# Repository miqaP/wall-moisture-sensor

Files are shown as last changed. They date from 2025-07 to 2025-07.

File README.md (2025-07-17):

# wall-moisture-sensor
https://github.com/miqaP/wall-moisture-sensor

# Versionning
Pour le moment j'ai une branche dev. Comment  
- Dev -> Release 

## Version de carte
Il faut se placer du point de vue de la carte et peut-être mettre de côté l'impact sur le firmware

- MAJOR -> Modification importantes -> Changement dans les fonctionnalités du produit -> feat:
    - Ajout d'une fonctionnalitées. Est-ce que l'ajout d'un connecteur est une nouvelle fonctionnalité ? Non je ne crois pas
    - Suppression d'une fonctionnalitées

- MINOR -> Pas de modification de fonctionnalité -> design:
    - Modification de composant, qui necessite la modification du routage par exemple changement de référence d'un DC/DC -> Mais pas de changement dans la fonctionnalité
    - Optimisation du layout, déplacement des composants
    - Changement du layout pour s'intégrer dans un boitier
    - Changement de la sérigraphie
- PATCH -> Modification de la BOM -> bom
    - Ok mais des fois la modification de la BOM implique une modification du firmware, nan ?

# Continuous Integration
Voir https://sschueller.github.io/posts/ci-cd-with-kicad-and-gitlab/
https://github.com/LiveLeds/AstraDriver/tree/main

Liste des commandes qui doivent être lancées par la CI : 
- kicad-cli pcb drc wall_moisture-hardware.kicad_pcb
-  kicad-cli pcb export gerbers wall_moisture-hardware.kicad_pcb -o gerbers/
- kicad-cli render wall_moisture-hardware
- kicad-cli render wall_moisture-hardware.kicad_pcb
- kicad-cli pcb render wall_moisture-hardware.kicad_pcb
- kicad-cli pcb render wall_moisture-hardware.kicad_pcb --output 3drender/top.png -> Il faut faire les autres vues, les orientations et distances de la caméra vont dépendre de la taille du projet. Un script python pourrait determiner ces informations

L'intégration se lance lors de la création d'une release

Chose a réaliser: 
- Un rapport de release qui montre la différence entre la version actuelle et la version précedente -> Voir Kicad-diff
    - Il faut pouvoir détérminer la version précédente, comment faire ?
- Exporter les pdf des schémas et du hardware ( les couches du PCB et la carte complète)

# Note sur la configuration du projet
Commitlint s’exécute à chaque commit grâce au hook Git commit-msg. Ce hook est un script situé dans le dossier .git/hooks/commit-msg qui est automatiquement lancé par Git à la validation d’un commit. Ce script appelle Commitlint pour vérifier que le message du commit respecte les règles définies.

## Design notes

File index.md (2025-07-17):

---
layout: home
title: Home
---

{% assign project = site.project %}
{% assign cacheBust = site.time | date:'?v=%s' %}

Main Render

{{ project.description }}




## Table of Contents
{% for section in project.sections %}
- [{{ section.title }}](#{{ section.anchor }})
{% endfor %}

{% for render in project.renders %}
### {{ render.title }}
{{ render.title }}
{% endfor %}

### Schematic
{% for variant in project.schematic_variants %}
- [{{ variant.name }} PDF]({{ "/documents/" | append: project.name | append: variant.file_suffix | absolute_url | append: cacheBust }})
{% endfor %}

### Assembly
{% for variant in project.assembly_variants %}
- [{{ variant.name }} PDF]({{ "/documents/" | append: project.name | append: variant.file_suffix | absolute_url | append: cacheBust }})
{% endfor %}

### Interactive BOM
[IBOM HTML]({{ "/export/" | append: project.name | append: "-ibom.html" | absolute_url | append: cacheBust }})

### BOM
[BOM HTML]({{ "/export/" | append: project.name | append: "-bom.html" | absolute_url | append: cacheBust }})

### Downloads
{% for manufacturer in project.manufacturers %}
#### {{ manufacturer }}
- [{{ manufacturer }} Zip]({{ "export/" | append: project.name | append: "-" | append: manufacturer | append: ".zip" | absolute_url | append: cacheBust }})
- [BOM CSV]({{ "export/" | append: project.name | append: "_bom_" | append: manufacturer | downcase | append: ".csv" | absolute_url | append: cacheBust }})
- [CPL CSV]({{ "export/" | append: project.name | append: "_cpl_" | append: manufacturer | downcase | append: ".csv" | absolute_url | append: cacheBust }})
{% endfor %}

#### 3D Step
- [STEP File]({{ "/" | append: project.name | append: "-3D.step" | absolute_url | append: cacheBust }})

## Reports
{% include_relative erc_validation.md %}
{% include_relative drc_validation.md %}
{% include_relative report.md %}

{% if project.known_issues %}
## Known Issues
{{ project.known_issues | markdownify }}
{% endif %}

## Credits
{{ project.credits | markdownify }}

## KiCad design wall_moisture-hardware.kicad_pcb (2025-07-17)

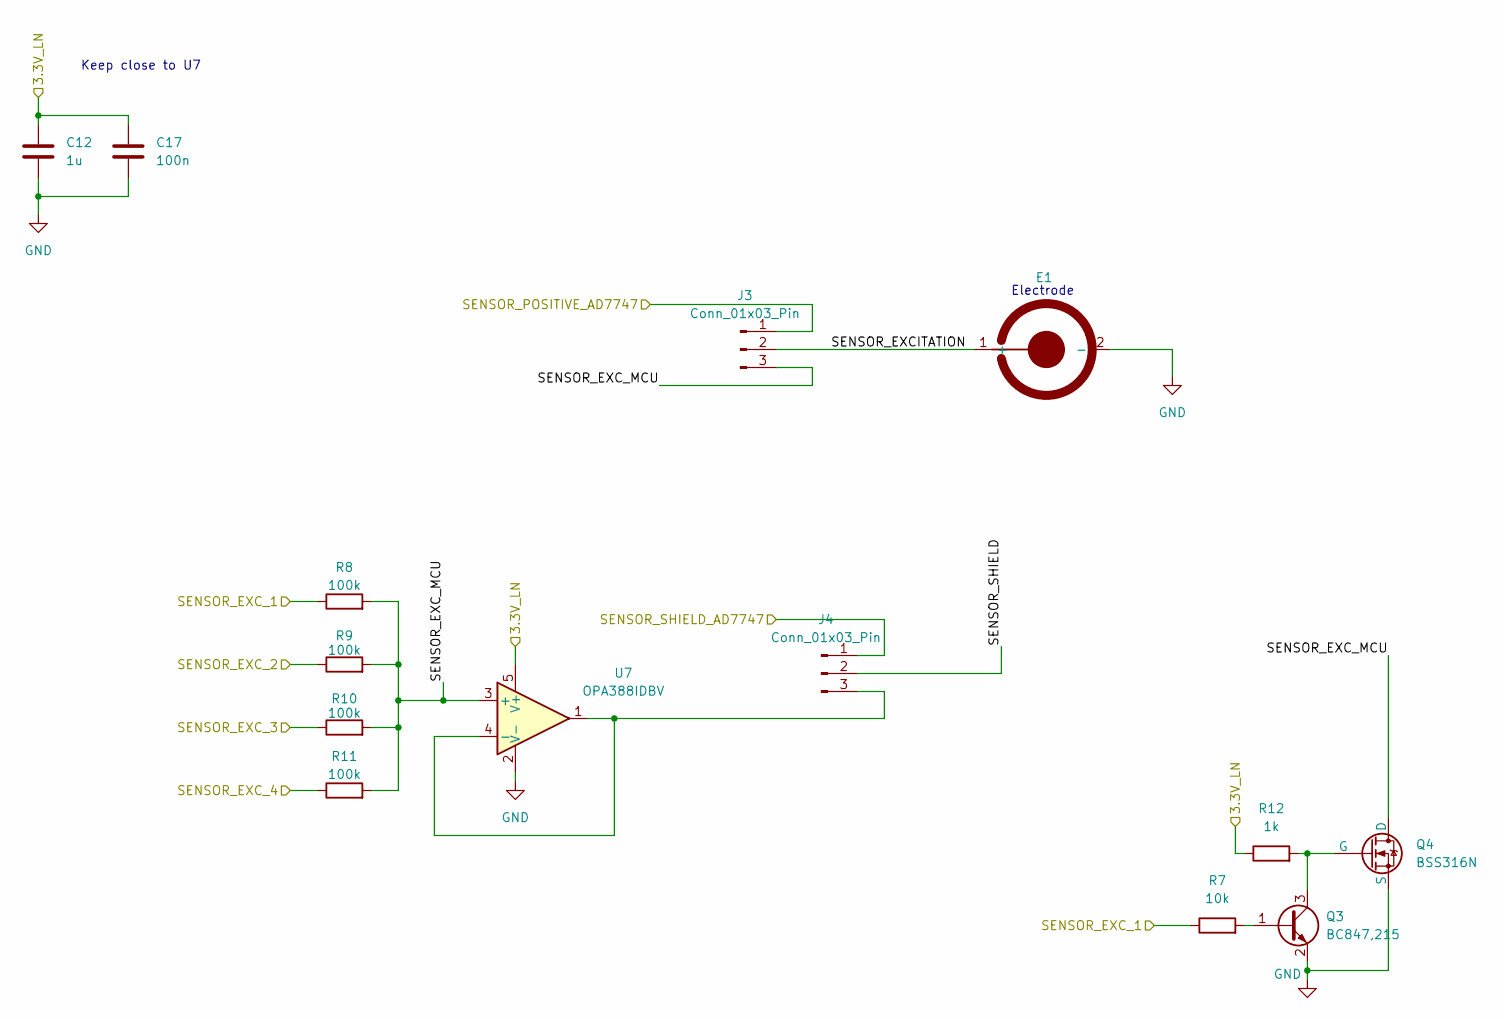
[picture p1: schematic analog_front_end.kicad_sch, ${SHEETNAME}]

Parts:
C12: 1u; C_0603_1608Metric
C17: 100n; C_0603_1608Metric
E1: CapacitiveElectrode-round_20mmx70mm
J3, J4: Conn_01x03_Pin; PinHeader_1x03_P2.54mm_Vertical
Q3: BC847,215; SOT-23
Q4: BSS316N; SOT-23
R7: 10k; R_0603_1608Metric
R8, R9, R10, R11: 100k; R_0603_1608Metric
R12: 1k; R_0603_1608Metric
U7: OPA388IDBV; SOT-23-5

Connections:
/Analog frontend/3.3V_LN: C12.1, C17.1, R12.1, U7.5 (V+); also elsewhere on the board
/Analog frontend/SENSOR_EXCITATION: E1.1 (+), J3.2
/Analog frontend/SENSOR_EXC_MCU: J3.3, Q4.1 (D), R8.2, R9.2, R10.2, R11.2, U7.3 (+)
/Analog frontend/SENSOR_POSITIVE_AD7747: J3.1; also elsewhere on the board
/Analog frontend/SENSOR_SHIELD: J4.2
/Analog frontend/SENSOR_SHIELD_AD7747: J4.1; also elsewhere on the board
/µC and digital/TIM1_CH1: R7.1, R8.1; also elsewhere on the board
/µC and digital/TIM1_CH2: R9.1; also elsewhere on the board
/µC and digital/TIM1_CH3: R10.1; also elsewhere on the board
/µC and digital/TIM1_CH4: R11.1; also elsewhere on the board
GND: C12.2, C17.2, E1.2 (-), Q3.2 (E), Q4.3 (S), U7.2 (V-); also elsewhere on the board
unnamed: J4.3, U7.1, U7.4 (-)
unnamed: Q3.1 (B), R7.2
unnamed: Q3.3 (C), Q4.2 (G), R12.2

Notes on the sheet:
Keep close to U7
Electrode

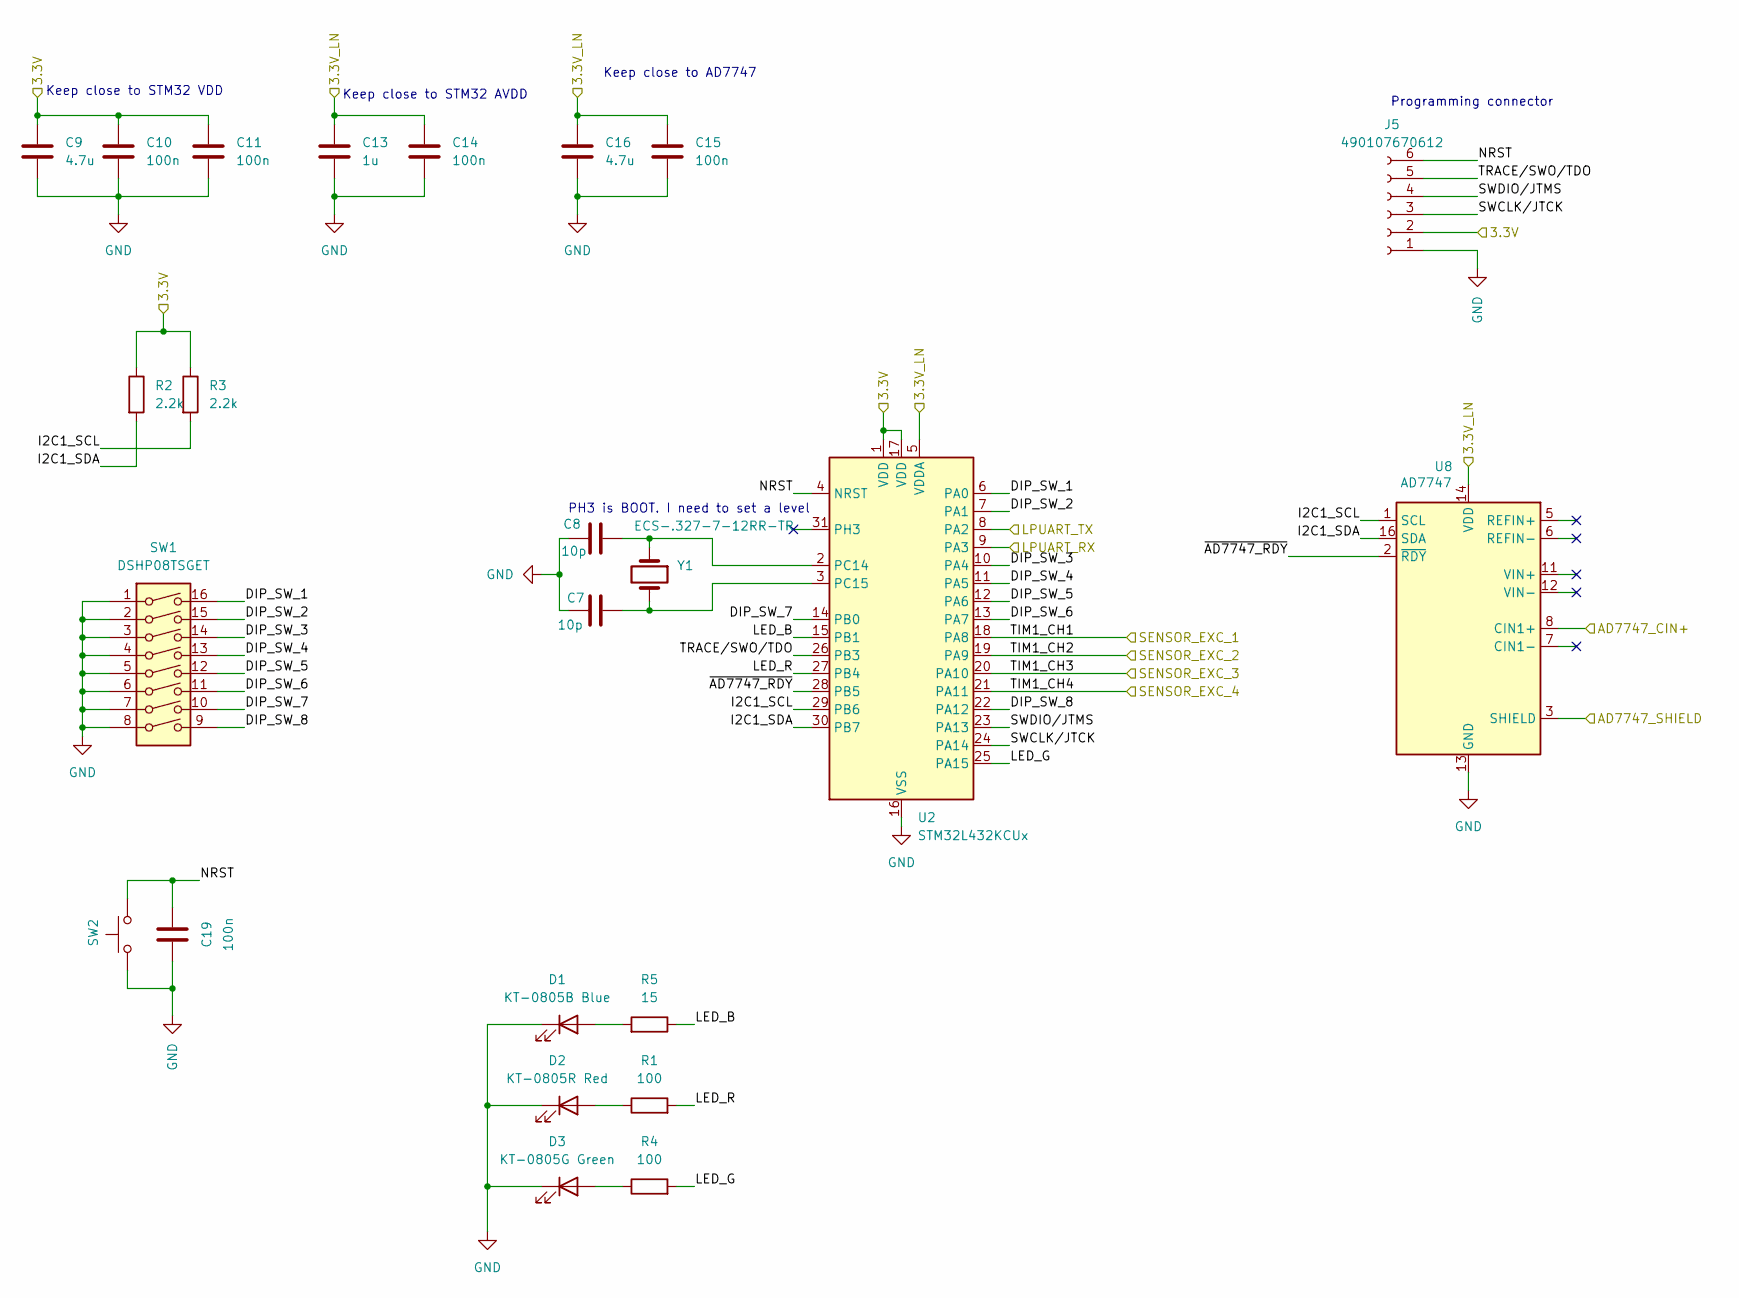
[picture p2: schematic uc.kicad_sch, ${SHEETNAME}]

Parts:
C7, C8: 10p; C_0603_1608Metric
C9, C16: 4.7u; C_0603_1608Metric
C10, C11, C14, C15, C19: 100n; C_0603_1608Metric
C13: 1u; C_0603_1608Metric
D1: KT-0805B Blue; LED_0805_2012Metric; LCSC C2293
D2: KT-0805R Red; LED_0805_2012Metric; LCSC C2295
D3: KT-0805G Green; LED_0805_2012Metric; LCSC C2297
J5: 490107670612; Skedd490107670612_2x06_P2.54mm_Debug
R1, R4: 100; R_0603_1608Metric
R2, R3: 2.2k; R_0603_1608Metric
R5: 15; R_0603_1608Metric
SW1: DSHP08TSGET; SW_DIP_SPSTx08_Slide_KingTek_DSHP08TJ_W5.25mm_P1.27mm_JPin
SW2: FSMH; SW_Tactile_SPST_NO_Straight_CK_PTS636Sx25SMTRLFS
U2: STM32L432KCUx; QFN-32-1EP_5x5mm_P0.5mm_EP3.45x3.45mm
U8: AD7747; TSSOP-16_4.4x5mm_P0.65mm
Y1: ECS-.327-7-12RR-TR; Crystal_SMD_2012-2Pin_2.0x1.2mm

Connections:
/Analog frontend/3.3V_LN: C13.1, C14.1, C15.1, C16.1, U2.5 (VDDA), U8.14 (VDD); also elsewhere on the board
/Analog frontend/SENSOR_POSITIVE_AD7747: U8.8 (CIN1+); also elsewhere on the board
/Analog frontend/SENSOR_SHIELD_AD7747: U8.3 (SHIELD); also elsewhere on the board
/Connector and Power/3.3V: C9.1, C10.1, C11.1, J5.2, R2.1, R3.1, U2.1 (VDD), U2.17 (VDD); also elsewhere on the board
/Connector and Power/MASTER_RX: U2.8 (PA2); also elsewhere on the board
/Connector and Power/MASTER_TX: U2.9 (PA3); also elsewhere on the board
/µC and digital/DIP_SW_1: SW1.16, U2.6 (PA0)
/µC and digital/DIP_SW_2: SW1.15, U2.7 (PA1)
/µC and digital/DIP_SW_3: SW1.14, U2.10 (PA4)
/µC and digital/DIP_SW_4: SW1.13, U2.11 (PA5)
/µC and digital/DIP_SW_5: SW1.12, U2.12 (PA6)
/µC and digital/DIP_SW_6: SW1.11, U2.13 (PA7)
/µC and digital/DIP_SW_7: SW1.10, U2.14 (PB0)
/µC and digital/DIP_SW_8: SW1.9, U2.22 (PA12)
/µC and digital/I2C1_SCL: R3.2, U2.29 (PB6), U8.1 (SCL)
/µC and digital/I2C1_SDA: R2.2, U2.30 (PB7), U8.16 (SDA)
/µC and digital/LED_B: R5.1, U2.15 (PB1)
/µC and digital/LED_G: R4.2, U2.25 (PA15)
/µC and digital/LED_R: R1.2, U2.27 (PB4)
/µC and digital/NRST: C19.2, J5.6, SW2.2, U2.4 (NRST)
/µC and digital/SWCLK/JTCK: J5.3, U2.24 (PA14)
/µC and digital/SWDIO/JTMS: J5.4, U2.23 (PA13)
/µC and digital/TIM1_CH1: U2.18 (PA8); also elsewhere on the board
/µC and digital/TIM1_CH2: U2.19 (PA9); also elsewhere on the board
/µC and digital/TIM1_CH3: U2.20 (PA10); also elsewhere on the board
/µC and digital/TIM1_CH4: U2.21 (PA11); also elsewhere on the board
/µC and digital/TRACE/SWO/TDO: J5.5, U2.26 (PB3)
/µC and digital/~AD7747_RDY: U2.28 (PB5), U8.2 (~RDY)
GND: C7.1, C8.1, C9.2, C10.2, C11.2, C13.2, C14.2, C15.2, C16.2, C19.1, D1.1 (K), D2.1 (K), D3.1 (K), J5.1, SW1.1, SW1.2, SW1.3, SW1.4, SW1.5, SW1.6, SW1.7, SW1.8, SW2.1, U2.16 (VSS), U2.32 (VSS), U2.33 (VSS), U8.13 (GND); also elsewhere on the board
unnamed: D1.2 (A), R5.2
unnamed: D2.2 (A), R1.1
unnamed: D3.2 (A), R4.1
unnamed: C8.2, U2.2 (PC14), Y1.1
unnamed: C7.2, U2.3 (PC15), Y1.2

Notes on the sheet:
Keep close to STM32 VDD
Programming connector
Keep close to AD7747
Keep close to STM32 AVDD
PH3 is BOOT. I need to set a level

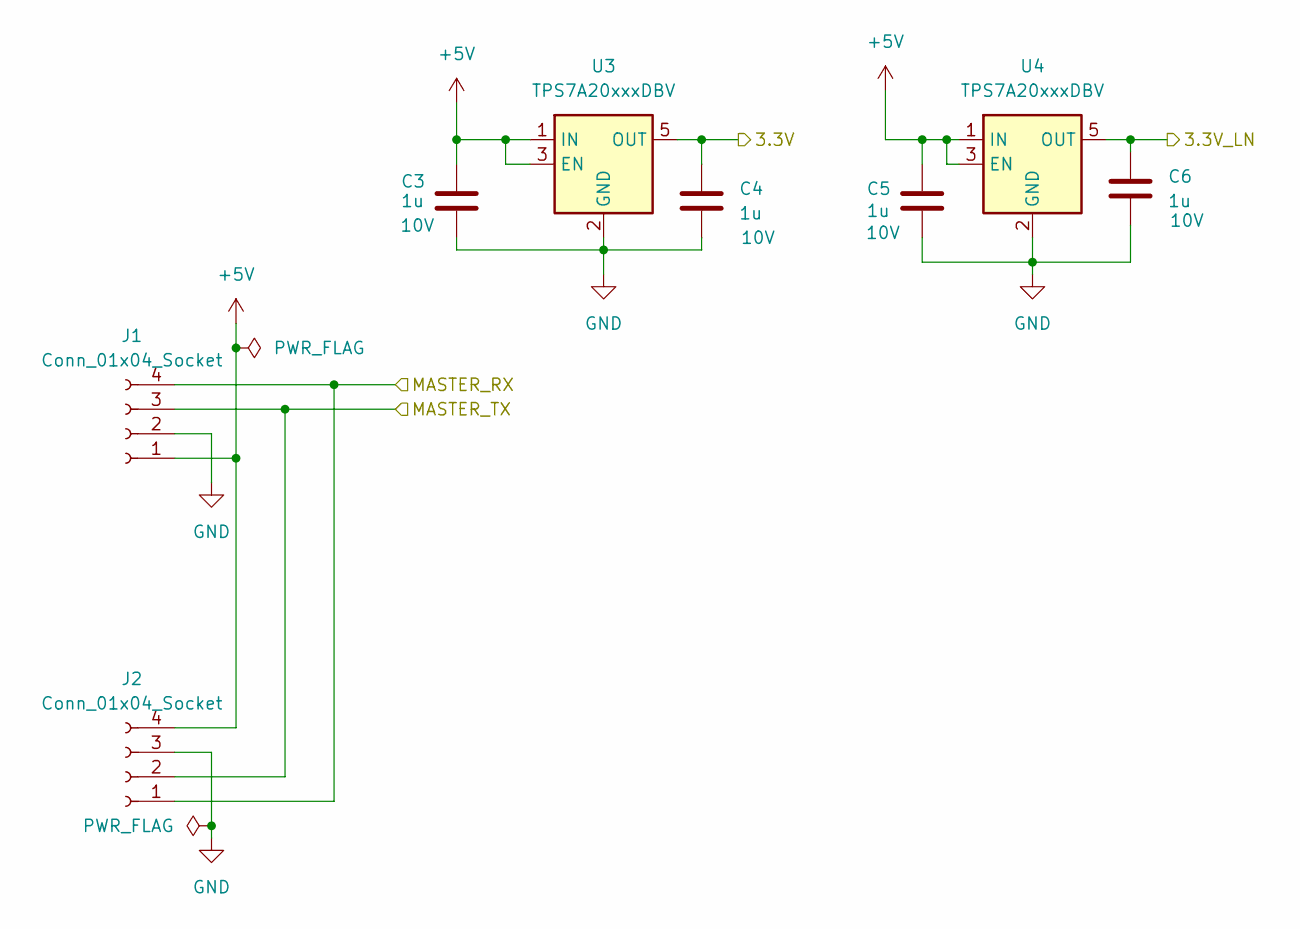
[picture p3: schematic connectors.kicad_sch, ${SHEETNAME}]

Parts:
C3, C4, C5, C6: 1u; C_0603_1608Metric
J1, J2: Conn_01x04_Socket; JST_PH_S4B-PH-SM4-TB_1x04-1MP_P2.00mm_Horizontal
U3, U4: TPS7A20xxxDBV; SOT-23-5

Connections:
+5V: C3.1, C5.1, J1.1, J2.4, U3.1 (IN), U3.3 (EN), U4.1 (IN), U4.3 (EN)
/Analog frontend/3.3V_LN: C6.1, U4.5 (OUT); also elsewhere on the board
/Connector and Power/3.3V: C4.1, U3.5 (OUT); also elsewhere on the board
/Connector and Power/MASTER_RX: J1.4, J2.1; also elsewhere on the board
/Connector and Power/MASTER_TX: J1.3, J2.2; also elsewhere on the board
GND: C3.2, C4.2, C5.2, C6.2, J1.2, J2.3, U3.2 (GND), U4.2 (GND); also elsewhere on the board

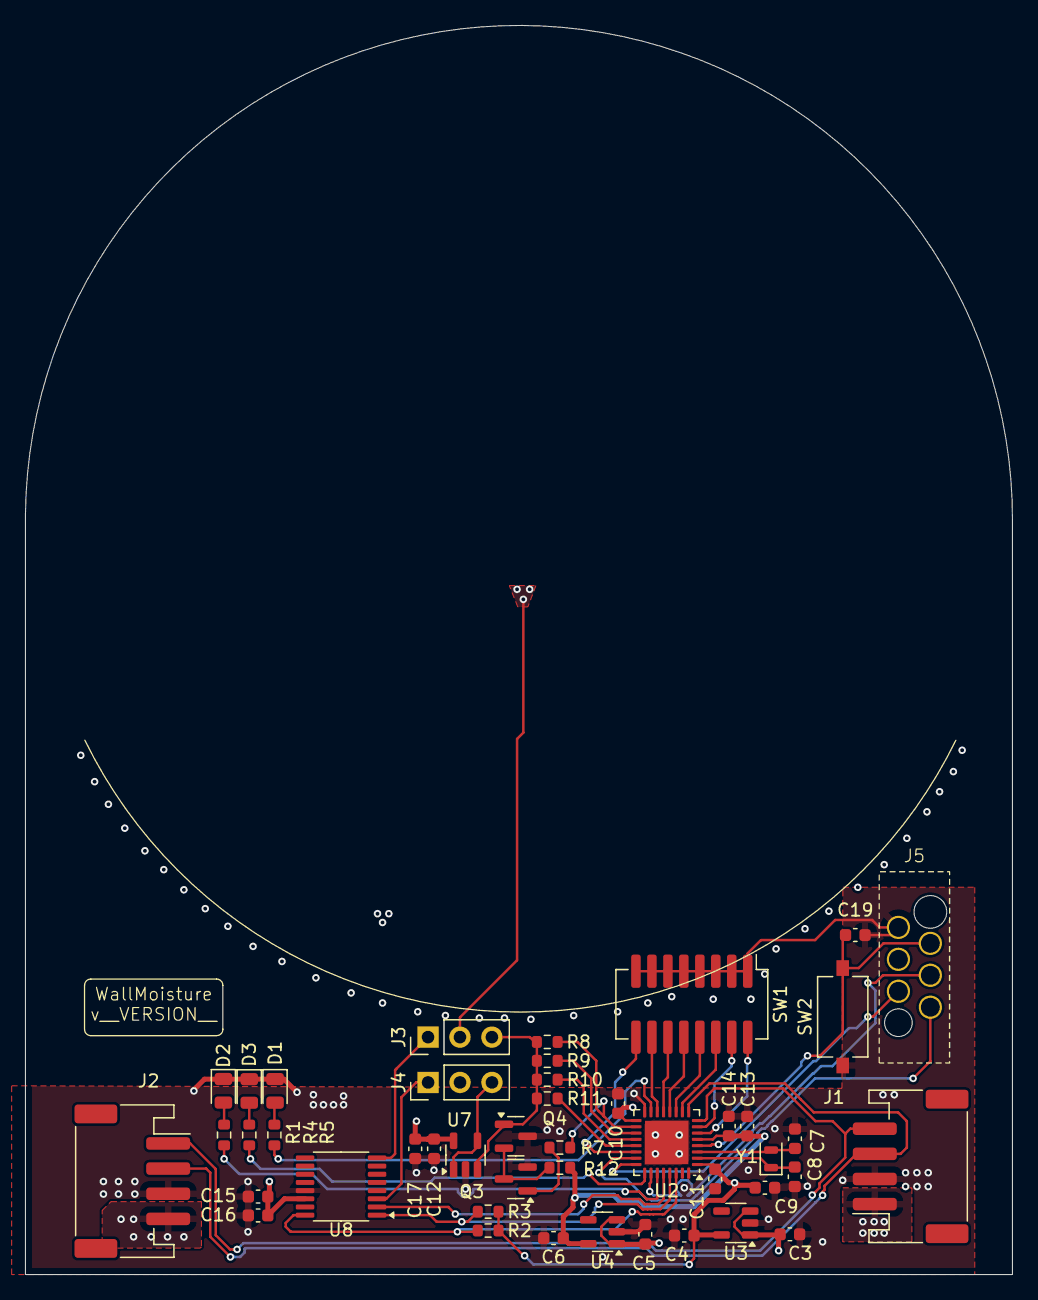
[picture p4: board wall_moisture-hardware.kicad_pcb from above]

Board: 4 copper layers, 78.5 x 99.3 mm, 46 parts (1 on the bottom side), 40 nets.

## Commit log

2025-04-05 First commit :
    [Connector.kicad_sch, analog_front_end.kicad_sch, uc.kicad_sch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]
2025-05-05 ci: Fix kibot pcb print configuration
2025-05-05 ci: fix pcb pdf path
2025-05-14 Fix board cutt layer
    [wall_moisture-hardware.kicad_pcb]
2025-05-14 design: fix board cut layer
    [wall_moisture-hardware.kicad_pcb]
2025-05-14 ci: Fix jekyll base url because the site is currently deployed at the root of netlify
2025-05-14 ci: attempt to add renders, schemtics and assembly variants in the project field
2025-05-15 silk: add board name and placeholder to version number
    [wall_moisture-hardware.kicad_pcb]
2025-05-17 rule-check: Fix the ERC errors and warnings
    [Connector.kicad_sch, analog_front_end.kicad_sch, uc.kicad_sch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]
2025-05-17 ci: filter out some erc warning that are meaning less in ci context
2025-07-11 ci: configure commitlint to enforce the commit convention defined for kicad projects
2025-07-11 design: fix some rules check
    [analog_front_end.kicad_sch, wall_moisture-hardware.kicad_pcb]
2025-07-11 ci: add bom commit type as patch release
2025-07-13 feature: add three led to notify the status of the device
    [uc.kicad_sch]
2025-07-13 design: complete the routing of the board
    [wall_moisture-hardware.kicad_pcb]
2025-07-13 design: fix some erc/drc
    [analog_front_end.kicad_sch]
2025-07-13 ci: change the ci to use the latest docker kicad image instead of using the dev image
    It is an attempt to fix the ci showing warning of not matching component between the board and the kicad library
2025-07-14 ci: ignoring a drc rule in ci due to missmatch between kicad kibot version and my version
2025-07-15 chore: fix the naming of connectors sheet file name
    [connectors.kicad_sch]
2025-07-15 ci: export footprints into the project to avoid lib_fooprint_mismatch warning
2025-07-15 chore: fix the naming of connectors sheet file name and the change the path of footprints
    [analog_front_end.kicad_sch, uc.kicad_sch, wall_moisture-hardware.kicad_pcb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]
2025-07-15 design: fix electrode footprint that was broken by the import operation
    [wall_moisture-hardware.kicad_pcb]
2025-07-16 chore: move the routing inside the sheet frame
    [wall_moisture-hardware.kicad_pcb]
2025-07-16 chore: move footprints in libraries folder
2025-07-16 chore: update project to use local footprint and symbols
    [analog_front_end.kicad_sch, connectors.kicad_sch, uc.kicad_sch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]
2025-07-16 design: change mosfet simulation model to use a generic model and useless remove erc exclusion
    [analog_front_end.kicad_sch]
2025-07-17 ci: trigger release action on every pull request not only those which change the pcb
